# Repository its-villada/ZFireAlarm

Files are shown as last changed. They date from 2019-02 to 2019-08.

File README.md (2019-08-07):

# ZFireAlarm
Sistema de sensores inalámbricos a ser distribuidos sobre el edificio de la institución educativa para lograr el objetivo inicial de red inalámbrica para sirenas de incendio.

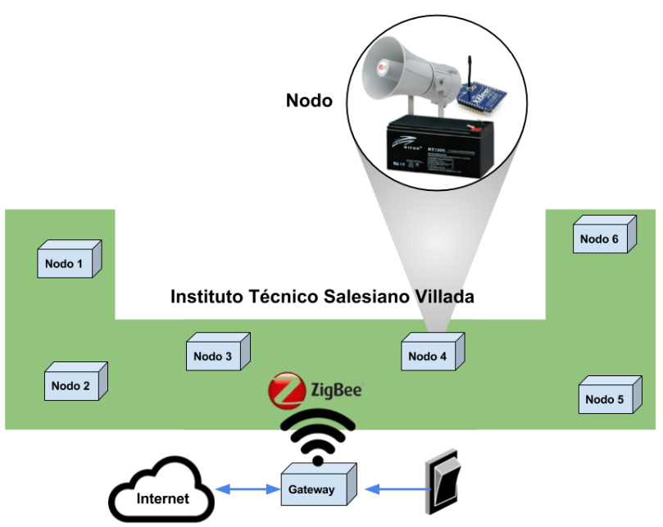
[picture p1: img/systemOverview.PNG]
System screenshot


## Objetivos
- Que el alumno se familiarice con las capacidades de los equipos XBee.
- Que sea capaz de diseñar una parte de un sistema real, que luego se montará en la práctica.
- Definir un presupuesto real para implementar un sistema completo y revisar posibilidades de implementación en base a disponibilidad en el mercado.
- Adquirir nociones generales sobre el hardware y software a utilizar en aplicaciones reales, a través del desarrollo de un ejercicio práctico aplicado a sensores y actuadores remotos. 

## Software y aplicaciones
- Python: https://www.python.org/
- Python-XBee: https://pypi.python.org/pypi/XBee
- XCTU: http://www.digi.com/products/xbee-rf-solutions/xctu-software/

## Arquitectura del sistema

### Gateway
El gateway debe estar montado con un Raspberry Pi (https://www.raspberrypi.org/) incluyendo un modulo XBee. En el siguiente link pueden encontrar un ejemplo de shield para XBee en la plataforma: https://www.cooking-hacks.com/ocumentation/tutorials/xbee-arduino-raspberry-pi-tutorial/

Las características son:
- El raspberry pi a utilizar es Raspberry Pi Model B+ (B PLUS) 512MB
- Conectividad ethernet (provista a través del Raspberry pi)
- Modulo XBee pro series 2: https://cdn-shop.adafruit.com/product-files/967/p967b+datasheet.pdf
- El shield de xbee provee un conector para puerto serie (idéntico al utilizado en las placas XBoard)
- Alimentado con fuente de alimentación externa
- Led indicador de alimentación.
- Entrada para pulsador externo (activación principal de la alarma de incendio).

### Nodos

Las características de los nodos son:
- Bateria 12V 7 A/H , las mismas que se utilizan en los sistemas de alarmas hogareño.
- Led indicador estado de batería
- Conector serie (idéntico al utilizado en las placas de evaluacion XBoard)
- Salida para alimentar una sirena 12V/24V 2A.
- Conectividad wireless brindada por módulo XBee pro series 2.

## Hardware
- Sirenas incendio
- Modulos XBee pro
- Modulo Raspberri pi
- Gabinete
- Bateria 12V 7AH

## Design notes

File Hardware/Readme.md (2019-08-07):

# Carpeta de proyecto en KiCad
Se incluye la librería del componente Xbee Pro

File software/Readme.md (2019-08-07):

# Archivos de programación XCTU - Xbee - Xboard

Archivos de ejemplo para programación de un coordinador y dos end device según el esquema de las fotos.

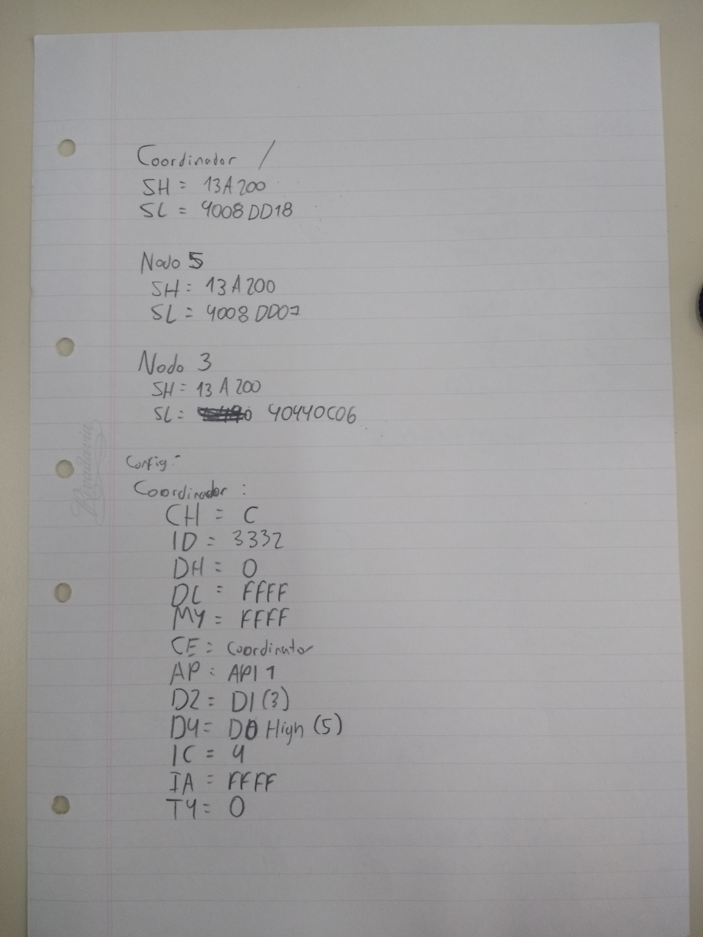
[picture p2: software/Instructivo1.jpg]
Instructivo1

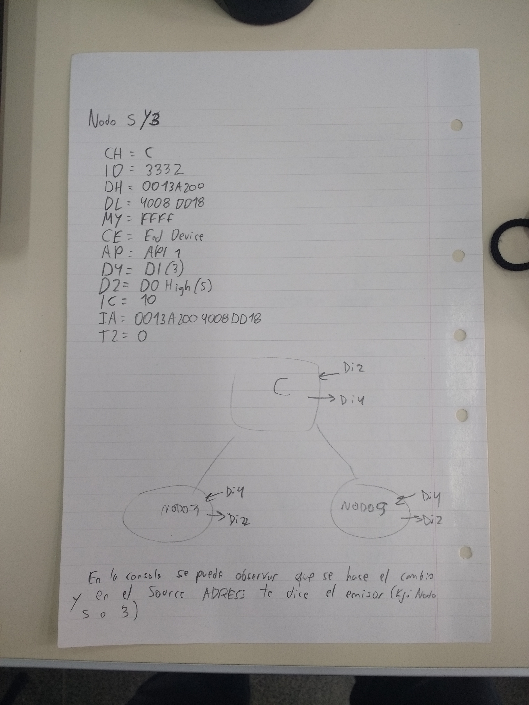
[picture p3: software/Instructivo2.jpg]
Instructivo2


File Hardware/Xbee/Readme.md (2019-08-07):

# Diseño en KiCad

Se utiliza una única placa con ambas funciones.
Esquemático en Xbee.pdf

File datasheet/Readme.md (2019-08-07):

# Documentación de placas y componentes del proyecto

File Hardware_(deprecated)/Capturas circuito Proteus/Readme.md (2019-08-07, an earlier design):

# Capturas de la placa en Proteus

Diseño anterior

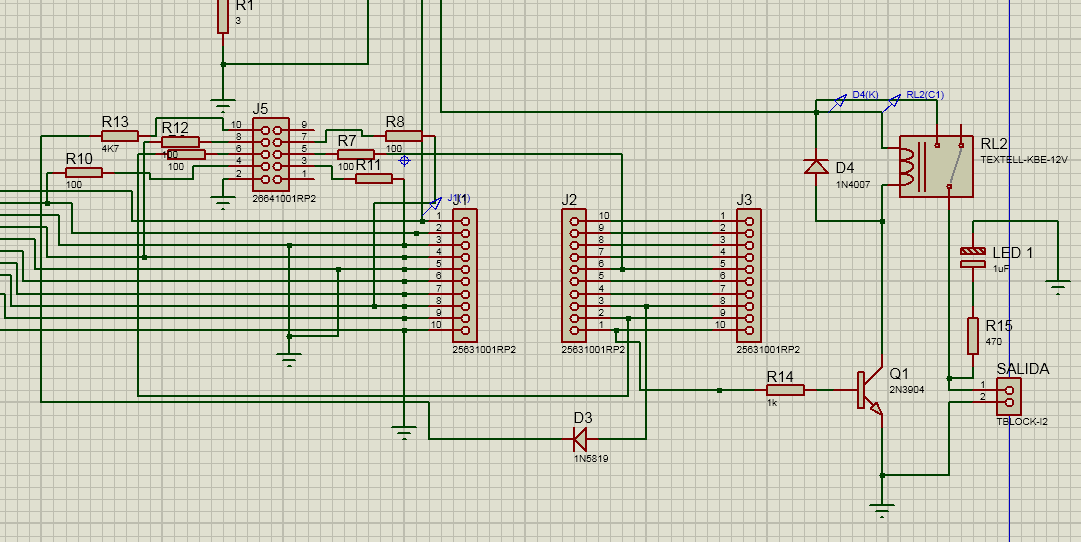
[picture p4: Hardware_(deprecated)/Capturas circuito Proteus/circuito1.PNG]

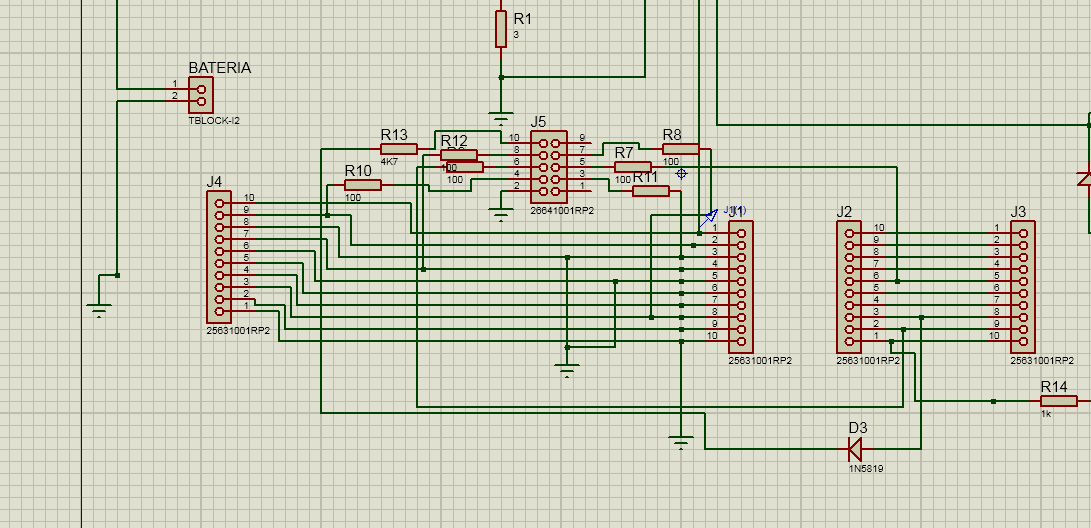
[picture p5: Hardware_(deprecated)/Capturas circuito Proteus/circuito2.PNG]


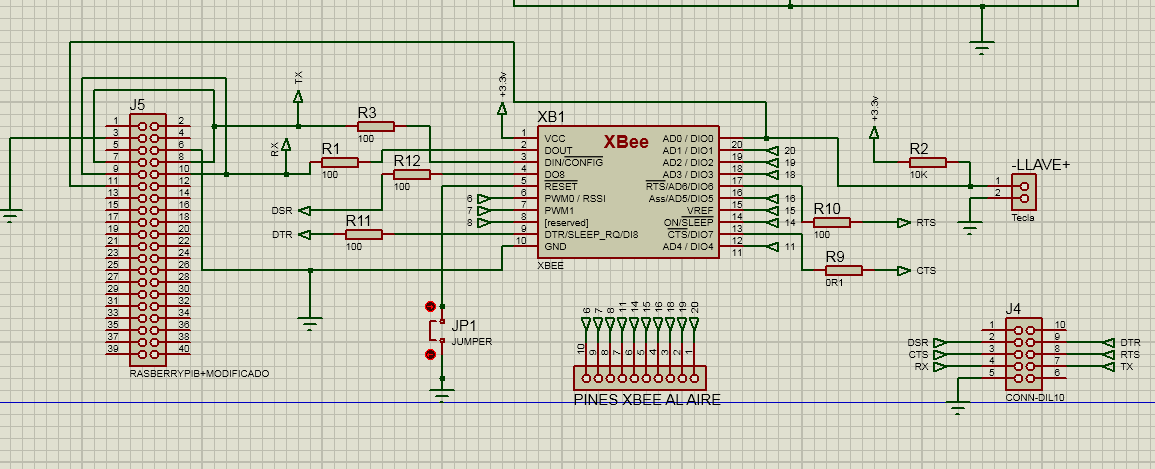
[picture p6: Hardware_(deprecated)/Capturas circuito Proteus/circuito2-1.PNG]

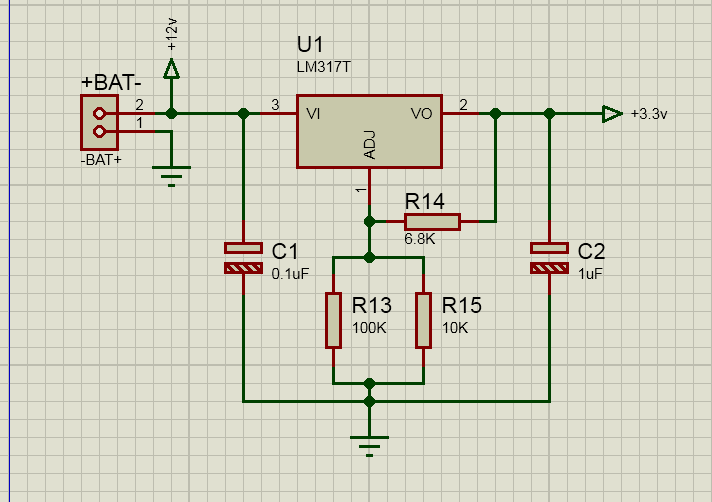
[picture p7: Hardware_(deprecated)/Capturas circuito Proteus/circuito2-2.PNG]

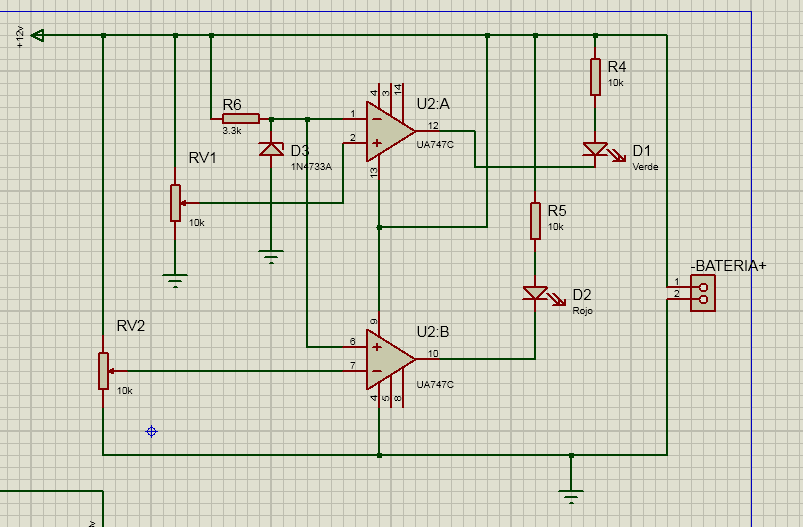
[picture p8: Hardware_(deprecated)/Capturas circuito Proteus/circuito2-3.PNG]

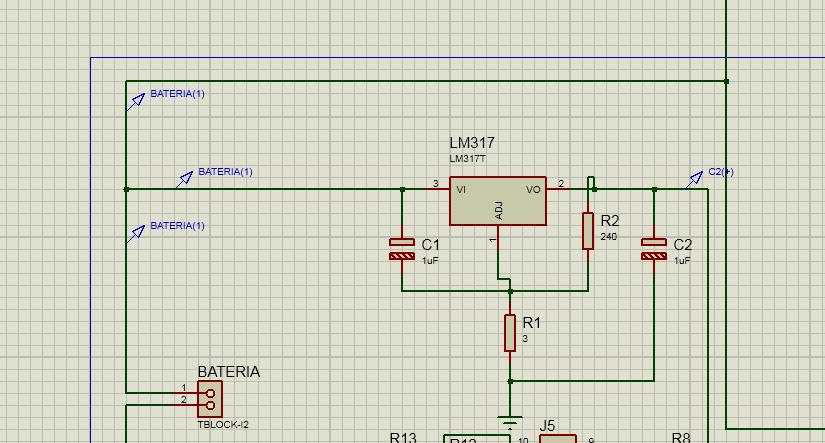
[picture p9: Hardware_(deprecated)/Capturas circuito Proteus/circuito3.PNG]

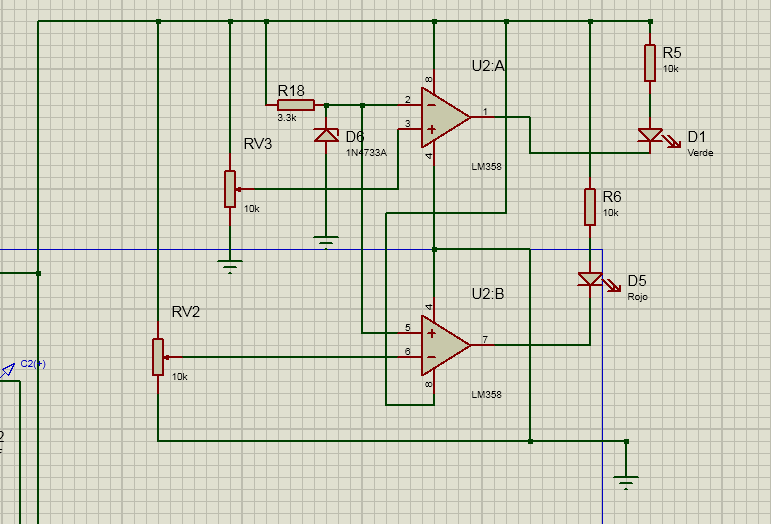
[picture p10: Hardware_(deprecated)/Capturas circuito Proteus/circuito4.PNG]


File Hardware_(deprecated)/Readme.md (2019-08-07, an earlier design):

# Archivos antiguos de diseño de placa

En esta versión, el nodo y el gateway eran placas diferentes diseñadas en proteus

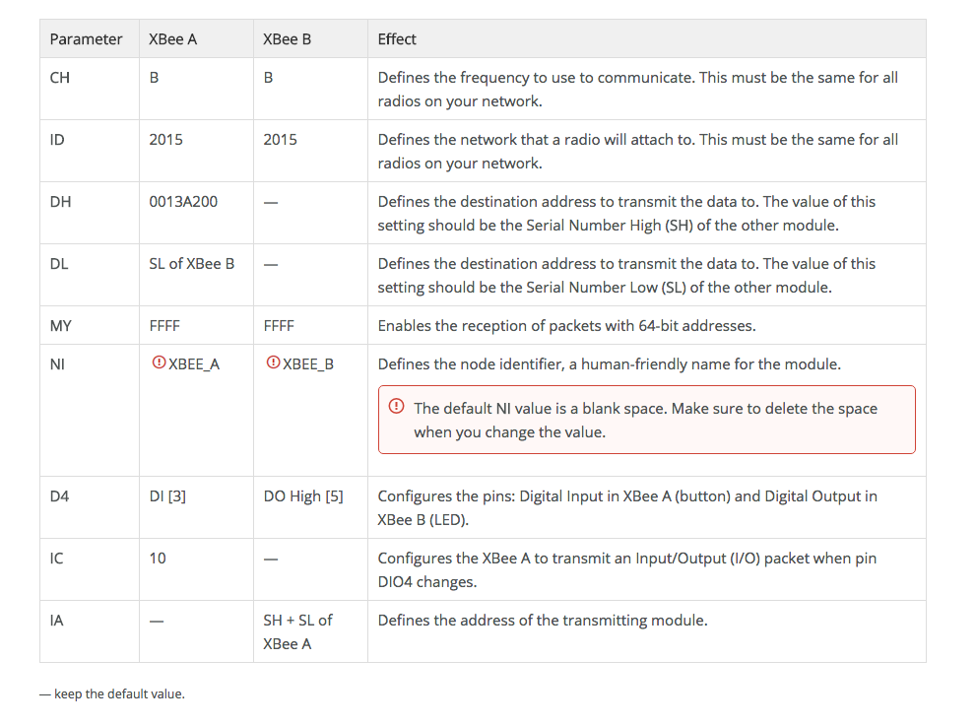
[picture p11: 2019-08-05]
datasheet/configuracion.png

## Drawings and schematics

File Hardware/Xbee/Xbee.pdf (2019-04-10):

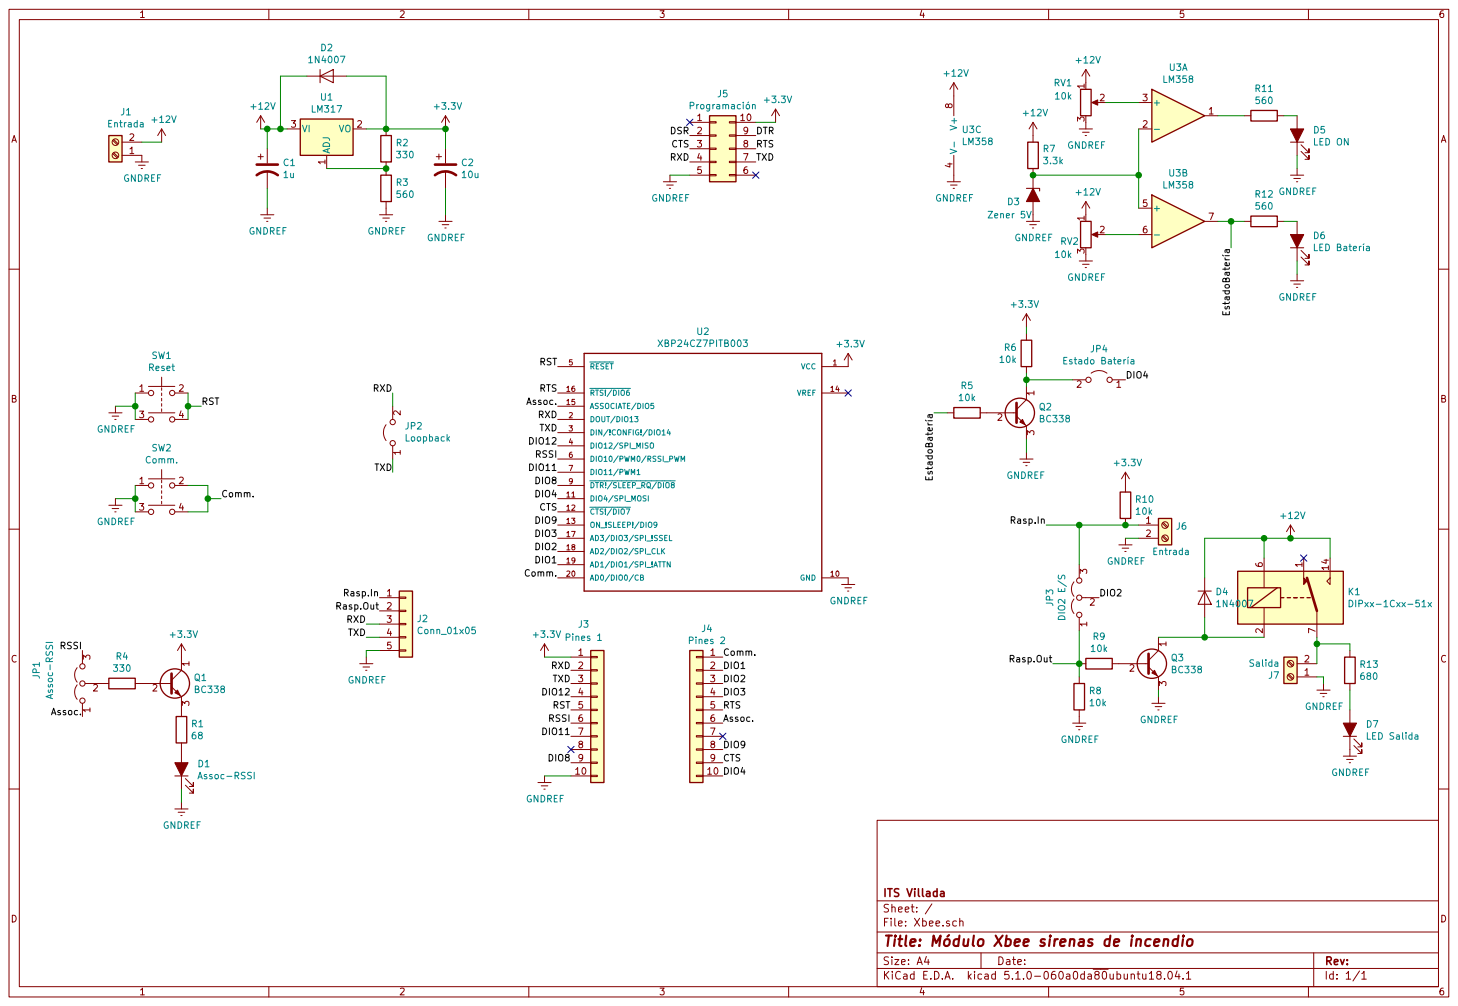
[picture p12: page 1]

ITS Villada
File: Xbee.sch Sheet: /
Id: 1/1 Title: Módulo Xbee sirenas de incendio

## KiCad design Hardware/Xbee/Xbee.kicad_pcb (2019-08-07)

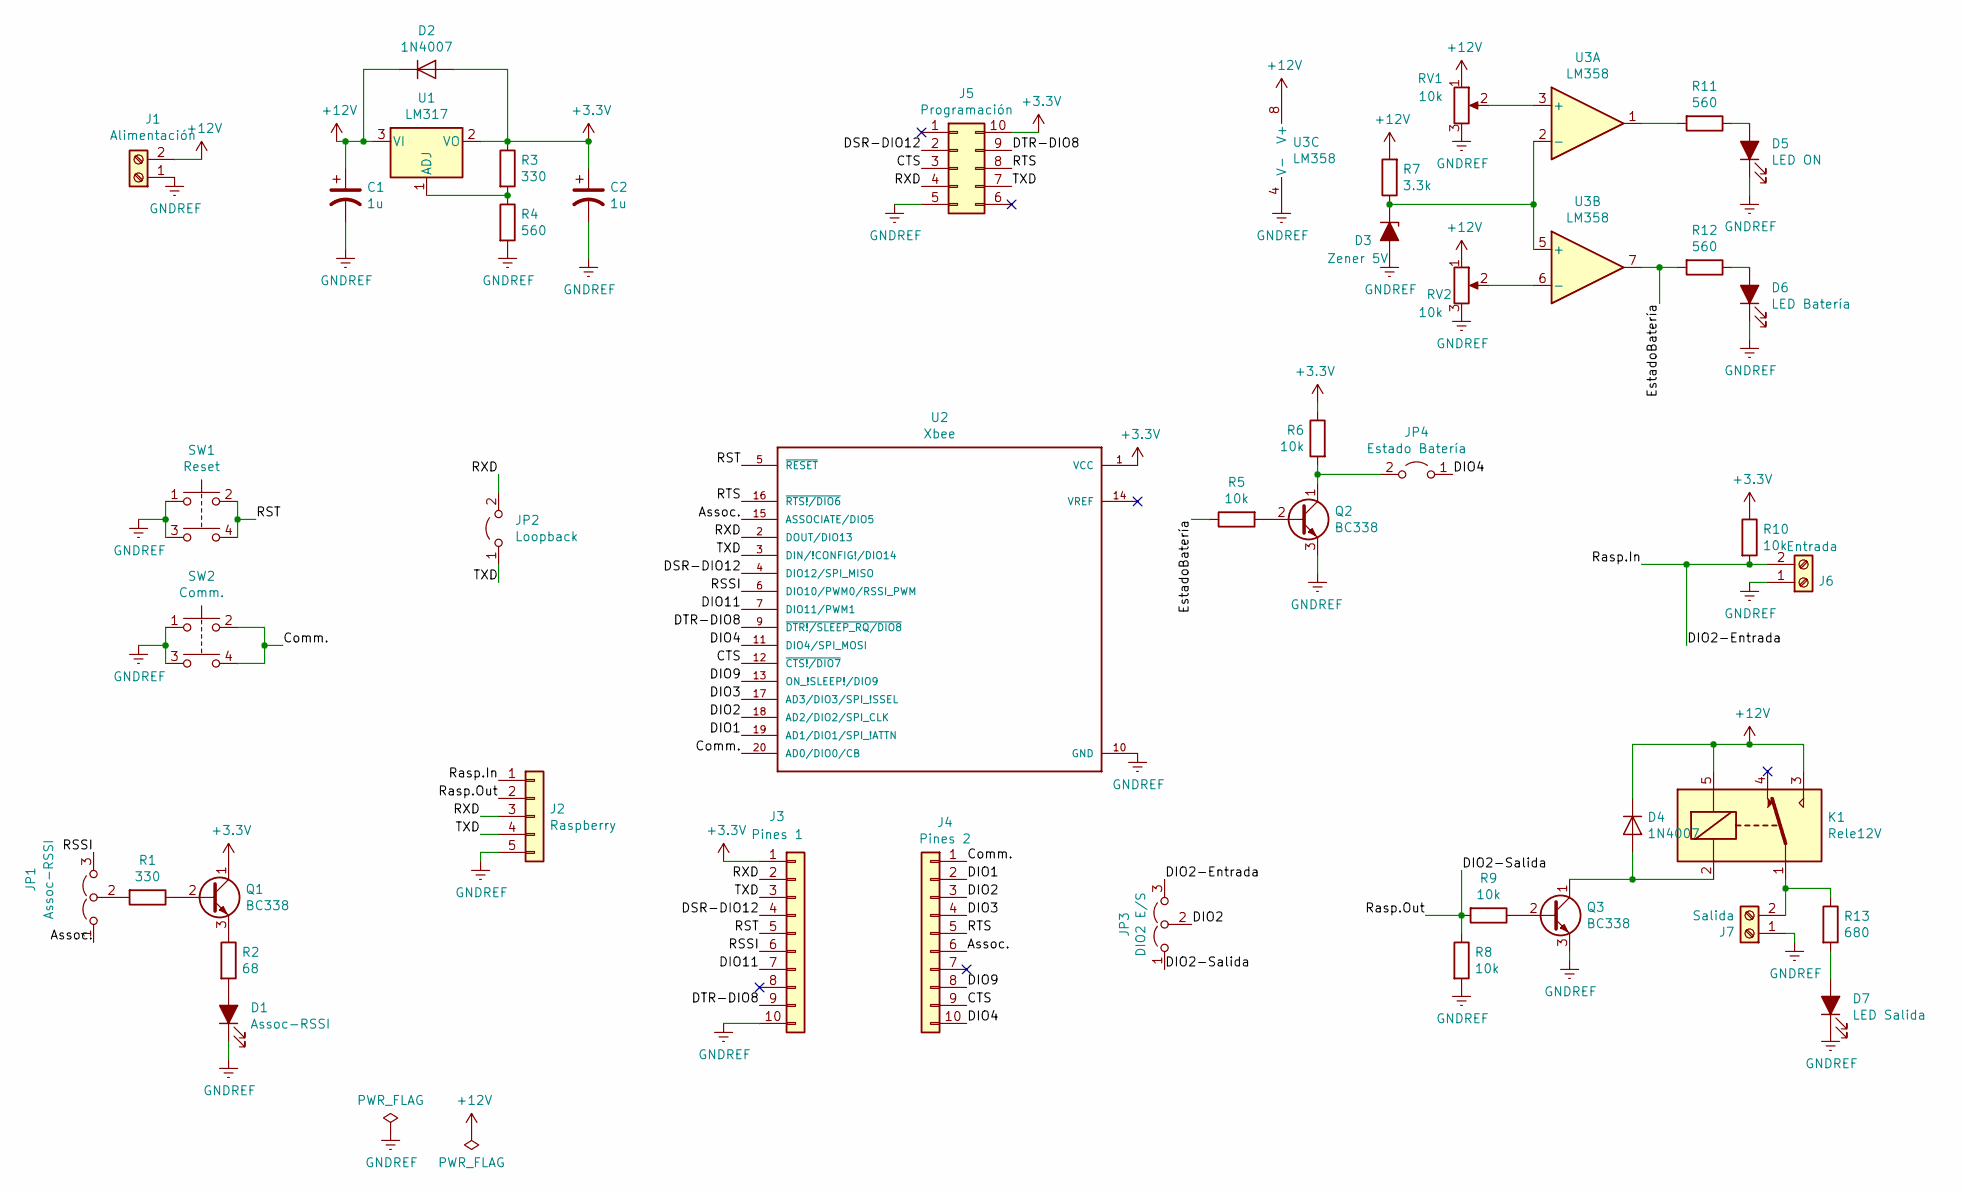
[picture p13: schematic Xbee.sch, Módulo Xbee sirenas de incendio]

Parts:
C1, C2: 1u; CP_Radial_D5.0mm_P2.50mm
D1: Assoc-RSSI; LED_D5.0mm
D2, D4: 1N4007; D_DO-41_SOD81_P10.16mm_Horizontal
D3: Zener 5V; D_DO-35_SOD27_P10.16mm_Horizontal
D5: LED ON; PinSocket_1x02_P2.54mm_Vertical
D6: LED Batería; PinSocket_1x02_P2.54mm_Vertical
D7: LED Salida; LED_D5.0mm
J1: Alimentación; TerminalBlock_bornier-2_P5.08mm
J2: Raspberry; PinHeader_1x05_P2.54mm_Vertical
J3: Pines 1; PinSocket_1x10_P2.54mm_Vertical
J4: Pines 2; PinSocket_1x10_P2.54mm_Vertical
J5: Programación; PinHeader_2x05_P2.54mm_Vertical
J6: Entrada; TerminalBlock_bornier-2_P5.08mm
J7: Salida; TerminalBlock_bornier-2_P5.08mm
JP1: Assoc-RSSI; PinHeader_1x03_P2.54mm_Vertical
JP2: Loopback; PinHeader_1x02_P2.54mm_Vertical
JP3: DIO2 E/S; PinHeader_1x03_P2.54mm_Vertical
JP4: Estado Batería; PinHeader_1x02_P2.54mm_Vertical
K1: Rele12V; Relay_SPDT_SANYOU_SRD_Series_Form_C
Q1, Q2, Q3: BC338; TO-92_Inline
R1, R3: 330; R_Axial_DIN0207_L6.3mm_D2.5mm_P10.16mm_Horizontal
R2: 68; R_Axial_DIN0207_L6.3mm_D2.5mm_P10.16mm_Horizontal
R4, R11, R12: 560; R_Axial_DIN0207_L6.3mm_D2.5mm_P10.16mm_Horizontal
R5, R6, R8, R9, R10: 10k; R_Axial_DIN0207_L6.3mm_D2.5mm_P10.16mm_Horizontal
R7: 3.3k; R_Axial_DIN0207_L6.3mm_D2.5mm_P10.16mm_Horizontal
R13: 680; R_Axial_DIN0207_L6.3mm_D2.5mm_P10.16mm_Horizontal
RV1, RV2: 10k; Potentiometer_Bourns_3386C_Horizontal
SW1: Reset; SW_TH_Tactile_Omron_B3F-10xx
SW2: Comm.; SW_TH_Tactile_Omron_B3F-10xx
U1: LM317; TO-220-3_Vertical
U2: Xbee; DIP2200W51P200L3294H279Q20P
U3: LM358; DIP-8_W7.62mm_Socket_LongPads

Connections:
+3V3: C2.1, D2.2 (A), J3.1, J5.10, Q1.1 (C), R3.1, R6.1, R10.1, U1.2 (VO), U2.1 (VCC)
+12V: C1.1, D2.1 (K), D4.1 (K), J1.2, K1.3, K1.5, R7.2, RV1.1, RV2.1, U1.3 (VI), U3.8 (V+)
/Assoc.: J4.6, JP1.1 (A), U2.15 (ASSOCIATE/DIO5)
/CTS: J4.9, J5.3, U2.12 (~CTS!/DIO7~)
/Comm.: J4.1, SW2.2, SW2.4, U2.20 (AD0/DIO0/CB)
/DIO1: J4.2, U2.19 (AD1/DIO1/SPI_!ATTN)
/DIO2: J4.3, JP3.2 (C), U2.18 (AD2/DIO2/SPI_CLK)
/DIO2-Entrada: J2.1, J6.2, JP3.3 (B), R10.2
/DIO2-Salida: J2.2, JP3.1 (A), R8.1, R9.2
/DIO3: J4.4, U2.17 (AD3/DIO3/SPI_!SSEL)
/DIO4: J4.10, JP4.1 (A), U2.11 (DIO4/SPI_MOSI)
/DIO9: J4.8, U2.13 (ON_!SLEEP!/DIO9)
/DIO11: J3.7, U2.7 (DIO11/PWM1)
/DSR-DIO12: J3.4, J5.2, U2.4 (DIO12/SPI_MISO)
/DTR-DIO8: J3.9, J5.9, U2.9 (~DTR!/SLEEP_RQ/DIO8~)
/EstadoBatería: R5.1, R12.2, U3.7
/RSSI: J3.6, JP1.3 (B), U2.6 (DIO10/PWM0/RSSI_PWM)
/RST: J3.5, SW1.2, SW1.4, U2.5 (~RESET~)
/RTS: J4.5, J5.8, U2.16 (~RTS!/DIO6~)
/RXD: J2.3, J3.2, J5.4, JP2.2 (B), U2.2 (DOUT/DIO13)
/TXD: J2.4, J3.3, J5.7, JP2.1 (A), U2.3 (DIN/!CONFIG!/DIO14)
GNDREF: C1.2, C2.2, D1.1 (K), D3.2 (A), D5.1 (K), D6.1 (K), D7.1 (K), J1.1, J2.5, J3.10, J5.5, J6.1, J7.1, Q2.3 (E), Q3.3 (E), R4.2, R8.2, RV1.3, RV2.3, SW1.1, SW1.3, SW2.1, SW2.3, U2.10 (GND), U3.4 (V-)
unnamed: D1.2 (A), R2.2
unnamed: D3.1 (K), R7.1, U3.2 (-), U3.5 (+)
unnamed: D4.2 (A), K1.2, Q3.1 (C)
unnamed: D5.2 (A), R11.1
unnamed: D6.2 (A), R12.1
unnamed: D7.2 (A), R13.2
unnamed: J7.2, K1.1, K1.8, R13.1
unnamed: JP1.2 (C), R1.2
unnamed: JP4.2 (B), Q2.1 (C), R6.2
unnamed: Q1.2 (B), R1.1
unnamed: Q1.3 (E), R2.1
unnamed: Q2.2 (B), R5.2
unnamed: Q3.2 (B), R9.1
unnamed: R3.2, R4.1, U1.1 (ADJ)
unnamed: R11.2, U3.1
unnamed: RV1.2, U3.3 (+)
unnamed: RV2.2, U3.6 (-)

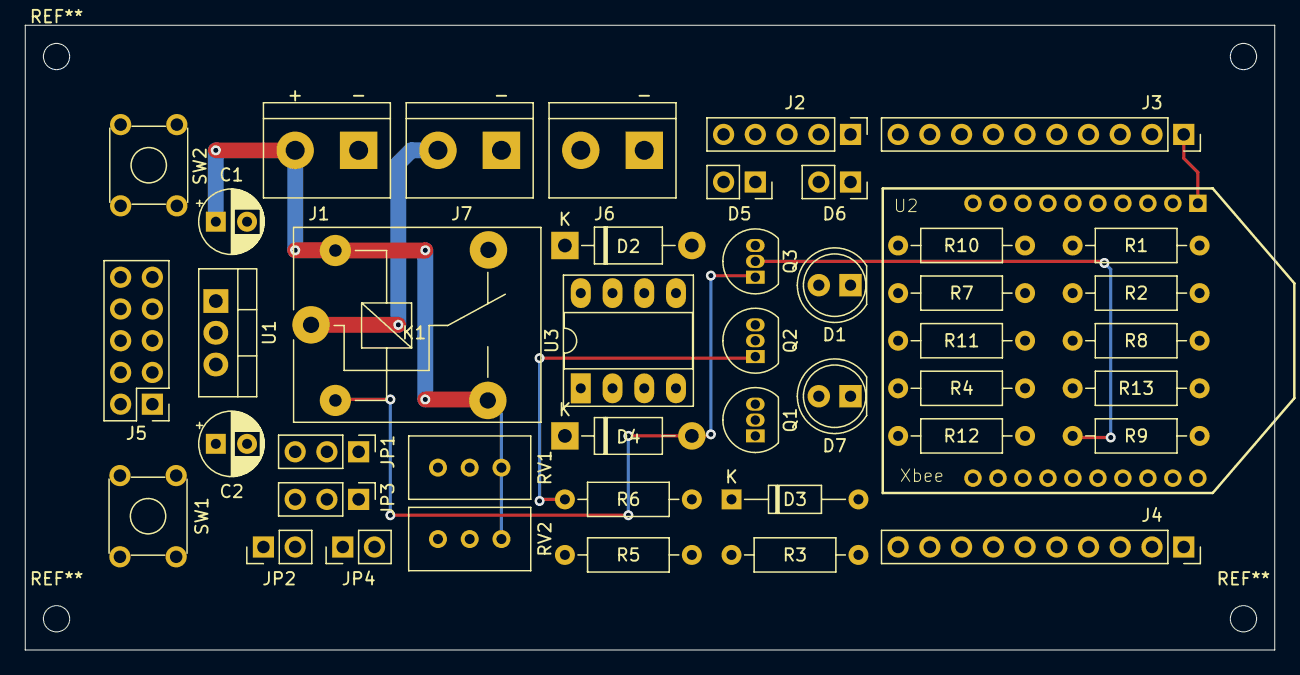
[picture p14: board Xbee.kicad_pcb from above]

Board: 2 copper layers, 100.0 x 50.0 mm, 44 parts (0 on the bottom side), 39 nets.

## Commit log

2019-04-10 Hardware en KiCad
    [Xbee.kicad_pcb, Xbee.sch]
2019-07-31 Testing sync
    [Xbee.sch]
2019-07-31 PCB design
2019-08-02 PCB footprint placement
    [Xbee.kicad_pcb]
2019-08-07 Started routing
    [Xbee.kicad_pcb, Xbee.sch]
